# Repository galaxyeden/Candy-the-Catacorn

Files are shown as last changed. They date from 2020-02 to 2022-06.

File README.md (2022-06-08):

# Candy the Catacorn 🐱 + 🦄

[Update - I'm currently planning a board revision to make this easier to make with more obtainable parts]

Catacorn Badge :D I don't care how you spell it, I've spelled it catacorn for years. Caticorn is equally valid! It's really small, and cute - but you should be able to program it to do a lot of things.

You can [order from OSH Park](https://oshpark.com/shared_projects/pnVDiM8w) - that's not a sponsored link, and they're by no means the cheapest place to order from, I only link as they're probably the cheapest way to get a small number of purple boards with a lead-free finish (good as they'll be handled!) - and their service has always been good to me.

## Background

I have wanted to learn more about electrical engineering and the 'hardware' side of things, so have started playing with dev boards including the Adafruit Trinket M0, which is the board that inspired this project. But none of them were catacorn enough, so I decided to make one :)

## Copyright/Liability

I'm not a lawyer, I believe everything I've based this on is licensed in a way I can draw inspiration, but let me know if you want me to get rid of something. All my work is Creative Commons, see license file. Also, I'm obviously not responsible for injuries or anything like that - this is definitely not a safety-tested, commercial project. Build at your own risk. It probably won't even work :)

## Basic Features

- ATSAMD21 microcontroller (ARM Cortext M0)
- Lots of LEDs, including two RGB ones (Dotstar-compatible)
- Two capacitive touch zones (ears)
- Native USB (you can even use it as a keyboard, hopefully)
- Probably a fair number of bugs and bad design decisions!

## Bill of Materials

| Component | Manufacturer | Qty |
|---|---|-----|
| This board | Whoever you choose | 1 |
| ATSAMD21E18A-AU-ND | Microchip Technology | 1 |
| S2B-PH-SM4-TB(LF)(SN) | JST | 1 |
| 1uF 0603 Capacitor | Any | 2 |
| 10uF 0603 Capacitor | Any | 2 |
| APA102-5050 or Equivalent (e.g. SK9822) | APA Electronic Co (or other) | 2 |
| JE2835AWT-00-0000-000A0ZF940E | Cree Inc | 2 |
| Pink LED 0805 | Generic | 2 |
| Turquoise LED 0805 | Generic | 3 |
| UV/Purple LED 0805 | Generic | 3 |
| AP2112K-3.3TRG1 | Diodes Incorporated | 1 |
| DSS14UTR | SMC Diode Solutions | 2 |
| USB3076-30-A | GCT | 1 |
| 150 Ohm 1206 Resistor | Any | 2 |
| 180 Ohm 0805 Resistor | Any | 2 |
| 180 Ohm 0603 Resistor | Any | 3 |
| 330 Ohm 0805 Resistor | Any | 3 |
| TL3342 Switch (or equivalent) | E-Switch (or generic) | 1 |

## How to use?

This board is intended to be used with either CircuitPython or [PlatformIO](https://platformio.org/). I have cloned and modified others [bootloader](https://github.com/MermaidAllie/uf2-samdx1/tree/master/build/alliecat_candythecatacorn) and [CircuitPython firmware](https://github.com/MermaidAllie/circuitpython/blob/5.0.x/ports/atmel-samd/build-alliecat_candythecatacorn/firmware.uf2). These are very similar to the Adafruit Trinket M0, just rebranded basically, and you can use Adafruit Trinket M0 bootloader/firmware with a lot of success (it's how I prototyped this).

I have also included PlatformIO code and board configuration.

## Thanks

Thank you to the following people:

- Ladyada and [Adafruit](https://learn.adafruit.com/how-to-program-samd-bootloaders/trinket-m0-wiring) - for building excellent products and teaching people electronics. I used a lot of Trinket M0's in prototyping this. Seriously, people, go buy their products - they're fantastic (and the boards are way cuter than some others, especially look at the Metro M4 Express - it's just adorable).

- Various inspirations for the catacorn, but especially to the kid who asked me to paint their face as a catacorn when I was face painting some years ago. It was the first time I really started thinking what the features of a catacorn should be like. I hope you're doing well today, and I wish you all the best in life :) - also to the many people who've drawn catacorns (and caticorns and unicats) online, and I've taken inspiration from.

- Also, on that note, credit to [Lisa Frank](https://lisafrank.com/) because cute Lisa Frank images were one of my childhood inspirations, and they're just awesome and made me like this style of art. A Google image search gave me more ideas for how to draw the board outline and even how to place components to be part of the art (e.g. using a capacitor as a nose, as one drawing I found had a very square nose). The purple Lisa Frank cat, especially, gave me the idea for how the whiskers could work on a component-kitty. And, only in Lisa Frank land do RGB LED cat eyes make sense :) 

- I found [this image from Freepik](https://www.freepik.com/free-vector/kawaii-style-unicorn-character-collection_4697393.htm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) which gave me inspiration for the general shape of the base (I needed something flatter than most to get the micro USB port in, and I liked how the cat's belly sat down) and head angle of the catacorn, and also for the style of the heart outline on the cheek. That said, Candy isn't a clone of anyone else's catacorn, with her tiny little horn and big glowing glittery heart, she has her own place in the world - and many others also provided inspiration. So credit to everyone who's drawn a catacorn that's in the first few pages of Google Images results :D

- [Emojipedia](https://emojipedia.org/) came in really useful to for bits of emoji-inspired inspiration, and the capacitive touch zones (which are the heart emoji from a font on my system).

- Q - for being an awesome friend who has helped with so much of the EDA side of working this all out. Thank you for answering late night messages with silly questions!

- Charlie - for coming up with the name Candy! I love you bestie :D Without your encouragement and inspiration, I wouldn't have achieved half the things I have with tech. Thank you <3

- JoJo Siwa - because the inspirational quote comes from one of your songs, and your concert on the [D.R.E.A.M. tour](https://www.jojodreamtour.com/) I went to in Cardiff was amazing. I'm not sure if it's your original quote tho, so I didn't quote it as you - I think I've heard it before? Either way, very inspiring performance! Keep things fun and positive and spread the positive energy, people!

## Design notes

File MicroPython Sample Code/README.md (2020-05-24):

# MicroPython Sample Code

This directory contains sample MicroPython files designed to run on [NyanPython](https://github.com/GalaxyAllie/nyanpython) (a fork of [CircuitPython](https://github.com/adafruit/circuitpython)).

## How to use

Rename the file to 'main.py' and copy to the NYANPY drive.

## Contributions Welcome!

Please add both your file and a description in this readme to your pull request 🧜‍♀️

## List of files

### purpletwinkle.py

The original demo file by @GalaxyAllie - this file is a demo of the capacitive touch and LEDs.

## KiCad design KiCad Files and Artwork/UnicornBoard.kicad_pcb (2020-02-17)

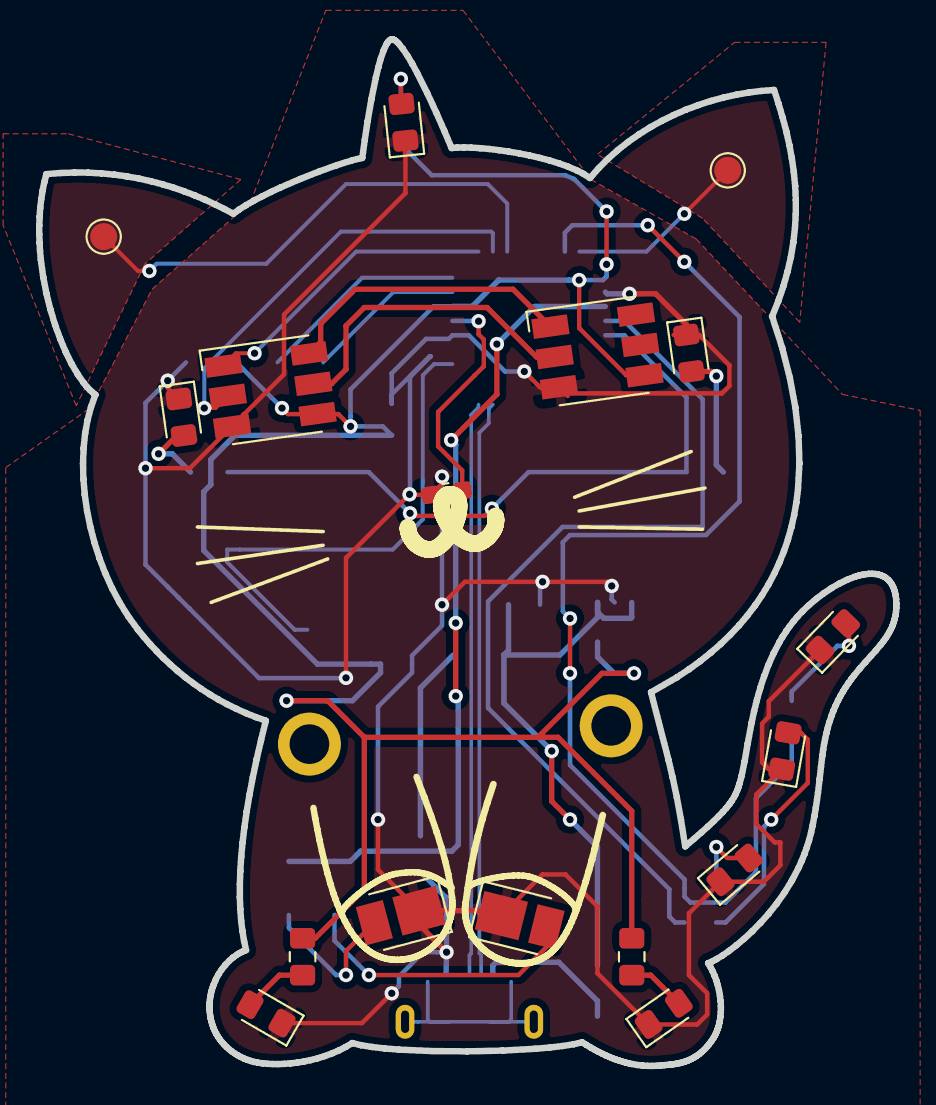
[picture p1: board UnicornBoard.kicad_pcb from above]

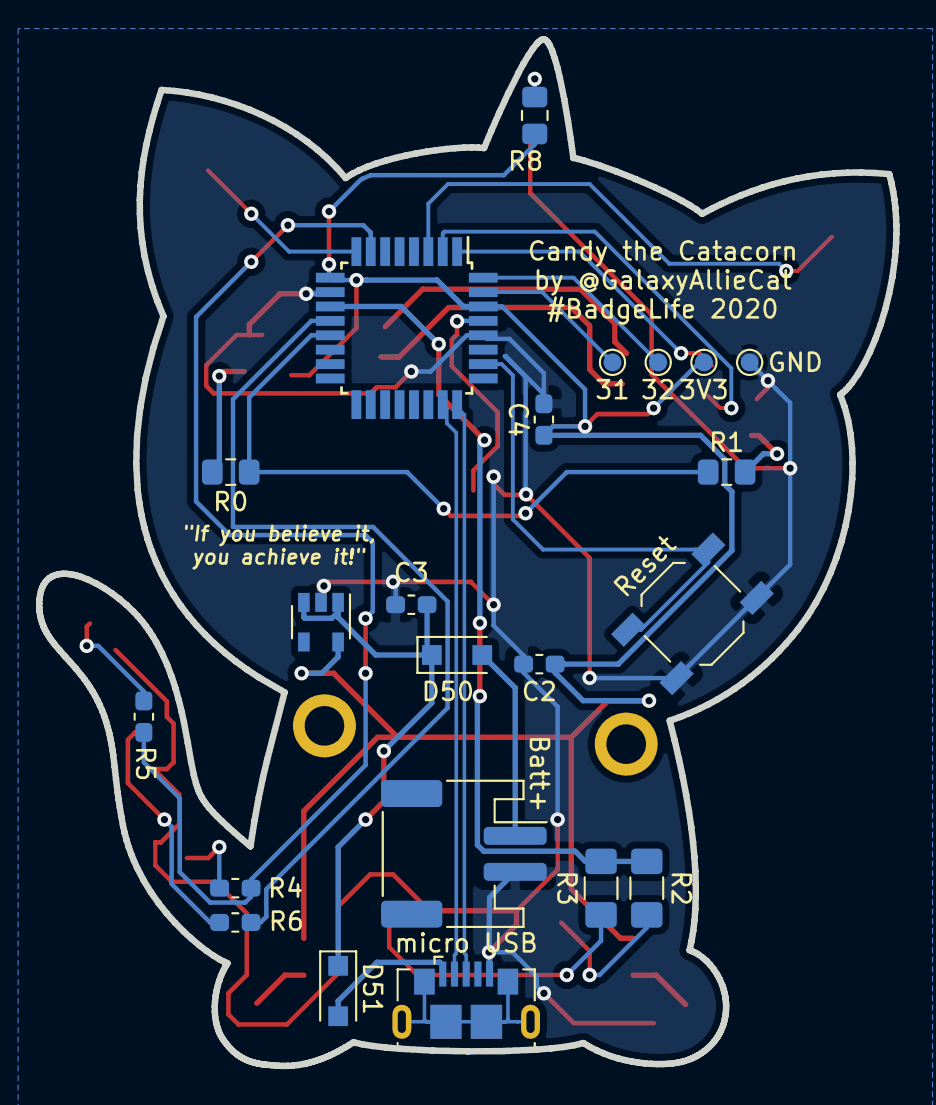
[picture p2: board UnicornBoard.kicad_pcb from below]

Board: 2 copper layers, 47.6 x 57.0 mm, 41 parts (22 on the bottom side), 31 nets.

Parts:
3V3, 31, 32: Conn_01x01; TestPoint_Pad_D1.0mm
Batt+: Battery; JST_PH_S2B-PH-SM4-TB_1x02-1MP_P2.00mm_Horizontal
C1, C4: 1 uF C; C_0603_1608Metric_Pad1.05x0.95mm_HandSolder
C2, C3: 10 uF C; C_0603_1608Metric_Pad1.05x0.95mm_HandSolder
D0, D1, D4, D5, D6, D7, D8, D9: LED; LED_0805_2012Metric_Pad1.15x1.40mm_HandSolder
D2, D3: LED; LED_PLCC_2835_Handsoldering
D50, D51: D_Schottky; D_SOD-123F
Dot1, Dot2: APA102; LED_RGB_5050-6
GND: Conn_01x01; TestPoint_Pad_D1.0mm
H1, H2: MountingHole; MountingHole_2.2mm_M2_ISO7380_Pad
R0, R1: 180R; R_0805_2012Metric_Pad1.15x1.40mm_HandSolder
R2, R3: 30R; R_1206_3216Metric_Pad1.42x1.75mm_HandSolder
R4, R5, R6: 100R; R_0603_1608Metric_Pad1.05x0.95mm_HandSolder
R7, R8, R9: 330R; R_0805_2012Metric_Pad1.15x1.40mm_HandSolder
Reset: SW_Push; SW_SPST_TL3342
Touch1, Touch2: MountingHole_Pad; TestPoint_Pad_D1.5mm
U1: ATSAMD21E18A-AU; TQFP-32_7x7mm_P0.8mm
U2: AP2112K-3.3; SOT-23-5
micro USB: USB_B_Micro; USB_Micro-B_GCT_USB3076-30-A

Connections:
+3V3: 3V3.1, C2.2, C4.1, Dot1.4, Dot2.4, R7.1, R8.1, R9.1, U1.9, U1.30, U2.5
+BATT: Batt+.1, D50.2
/USB_D+: U1.24, micro USB.3
/USB_D-: U1.23, micro USB.2
GND: Batt+.2, C1.1, C2.1, C3.2, C4.2, D0.1, D1.1, D2.1, D3.1, D4.1, D5.1, D6.1, D7.1, D8.1, D9.1, Dot1.3, Dot2.3, GND.1, Reset.2, U1.10, U1.28, U2.2, micro USB.5
unnamed: C1.2, U1.29
unnamed: C3.1, D50.1, D51.1, U2.1, U2.3
unnamed: D0.2, R0.2
unnamed: D1.2, R1.2
unnamed: D2.2, R2.1
unnamed: D3.2, R3.1
unnamed: D4.2, R4.2
unnamed: D5.2, R5.2
unnamed: D6.2, R6.2
unnamed: D7.2, R7.2
unnamed: D8.2, R8.2
unnamed: D9.2, R9.2
unnamed: Dot1.1, Dot2.6
unnamed: Dot1.2, Dot2.5
unnamed: Dot2.1, U1.1
unnamed: Dot2.2, U1.2
unnamed: 31.1, U1.31
unnamed: 32.1, U1.32
unnamed: R0.1, R1.1, U1.13
unnamed: R2.2, R3.2, U1.11
unnamed: R4.1, R5.1, U1.7
unnamed: R6.1, U1.12
unnamed: Reset.1, U1.26
unnamed: Touch1.1, U1.8
unnamed: Touch2.1, U1.3
VBUS: D51.2, micro USB.1

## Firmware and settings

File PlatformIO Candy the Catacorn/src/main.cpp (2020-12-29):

// C++ demo program for Candy the Catacorn
// https://galaxyallie.space/Candy-the-Catacorn/

#include <Arduino.h>
#include <SPI.h>
#include <Adafruit_DotStar.h>
#include <Adafruit_FreeTouch.h>
#include <adafruit_ptc.h>
#include <samd21_ptc_component.h>

#define NUMSTARS 2
#define STARDATA 7
#define STARCLOCK 8

int moving = 0;
int initialRTouchValue = 0;
int RtouchValue = 0;
int initialLTouchValue = 0;
int LtouchValue = 0;
int n = 30;
int k = 1;
int d = 1;
int i = 30;
int j = 255;
int modeSel = 0;
int light = 0;
int rtime = 0;
bool rainbowActive = false;

// Configure DotStar eyes and Adafruit FreeTouch for ears

Adafruit_DotStar stars = Adafruit_DotStar(NUMSTARS, STARDATA, STARCLOCK, DOTSTAR_BGR);
Adafruit_FreeTouch qt_1 = Adafruit_FreeTouch(A0, OVERSAMPLE_4, RESISTOR_50K, FREQ_MODE_NONE);
Adafruit_FreeTouch qt_2 = Adafruit_FreeTouch(A3, OVERSAMPLE_4, RESISTOR_50K, FREQ_MODE_NONE);

// Pin notes:
// - D0/A2 controls the white lights on the paws
// - D1/A0 is the right ear capacitive touch sensor
// - D3/A3 is the left ear capacitive touch sensor
// - D2/A1 is the first tail section
// - D4/A4 is the second tail section 
// - D13 is the corner of the eyes
// - The eyes are the internal DotStar pin

void setup() {
  Serial.begin(115200); // USB serial is used for diagnostics messages
  pinMode(13, OUTPUT); // Eye corners
  pinMode(0, OUTPUT); // White front paws
  pinMode(2, OUTPUT); // Tail section one
  pinMode(4, OUTPUT); // Tail section two
  stars.setBrightness(191); // 75% max brightness to reduce heat and aging of DotStars
  stars.begin();
  stars.show();
  if (! qt_1.begin()) {
    Serial.println("Failed to begin qt on pin A0");
  }
  if (! qt_2.begin()) {
    Serial.println("Failed to begin qt on pin A3");
  }
  initialRTouchValue = qt_1.measure();
  initialLTouchValue = qt_2.measure();
}

// Capacitive touch detection function for right ear (Candy's right)

bool RcapTouchDetect() {
    Serial.println("\n*** Touch Result ***");
    rtime = millis();
    RtouchValue = qt_1.measure(); 
    Serial.print("Right Ear: "); Serial.print(RtouchValue);
    Serial.print(" (");  Serial.print(millis() - rtime); Serial.println(" ms)");   
    if(RtouchValue > (initialRTouchValue + 100)){
        return true;
    }
    else{
        return false;
    }
}

// Capacitive touch detection function for left ear (Candy's left)

bool LcapTouchDetect() {
    Serial.println("\n*** Touch Result ***");
    rtime = millis();
    LtouchValue = qt_2.measure(); 
    Serial.print("Left Ear: "); Serial.print(LtouchValue);
    Serial.print(" (");  Serial.print(millis() - rtime); Serial.println(" ms)");   
    if(LtouchValue > (initialLTouchValue + 100)){
        return true;
    }
    else{
        return false;
    }
}

// Light show for main loop

void lightShow(int light) {
  if (light == 0)
  {
    n = n + k;
    if (n > 255)
    {
      k = -1;
      n = 255;
    }
    if (n < 30)
    {
      k = 1;
      n = 30;
    }
    for(int pixelSel = 0; pixelSel < NUMSTARS; pixelSel++){
      stars.setPixelColor(pixelSel, 10, 0, ((n / 12) + 3));
    }
    stars.show();
    analogWrite(13, (n / 8));
    analogWrite(0, (n / 20));
    analogWrite(2, (n / 8));
    analogWrite(4, (n / 8));
    delay(10);
  }
  if (light == 1)
  {
    n = n + k;
    if (n > 255)
    {
      k = -1;
      n = 255;
    }
    if (n < 30)
    {
      k = 1;
      n = 30;
    }
    for(int pixelSel = 0; pixelSel < NUMSTARS; pixelSel++){
      stars.setPixelColor(pixelSel, 0, ((n / 12) + 3), 15);
    }
    stars.show();
    analogWrite(13, (n / 8));
    analogWrite(0, (n / 20));
    analogWrite(2, (n / 8));
    analogWrite(4, (n / 8));
    delay(10);
  }
  if(light == 2)
  {
    for(int pixelSel = 0; pixelSel < NUMSTARS; pixelSel++){
      stars.setPixelColor(pixelSel, 5, 0, 5);
    }
    stars.show();
    analogWrite(13, 10);
    analogWrite(0, 255);
    analogWrite(2, 10);
    analogWrite(4, 10);
  }
  if(light == 3)
  {
    for(int pixelSel = 0; pixelSel < NUMSTARS; pixelSel++){
      stars.setPixelColor(pixelSel, 0, 10, 15);
    }
    stars.show();
    analogWrite(13, 10);
    analogWrite(0, 255);
    analogWrite(2, 10);
    analogWrite(4, 10);
  }
}

// Rainbow generator

void rainbowTime () {
  while (rainbowActive == true)
  {
    analogWrite(13, 2);
    analogWrite(0, 2);
    analogWrite(2, 2);
    analogWrite(4, 2);
    for(long rainBowStarColour = 28672; rainBowStarColour < 94207 && rainbowActive == true; rainBowStarColour += 256) 
    {
      uint32_t rainBowSel = stars.gamma32(stars.ColorHSV(rainBowStarColour));
        for(int pixelSel = 0; pixelSel < NUMSTARS && rainbowActive == true; pixelSel++)
        {
            stars.setPixelColor(pixelSel, rainBowSel);
        }
        stars.show();
        if(RcapTouchDetect() == false)
        {
          delay(30);
          if(RcapTouchDetect() == false)
          {
            rainbowActive = false;
          }
        }
        delay(40);
    }
    if(RcapTouchDetect() == false)
    {
      delay(30);
      if(RcapTouchDetect() == false)
      {
        rainbowActive = false;
      }
    }
  }
}

void loop() {
  if(RcapTouchDetect() == true) // Right ear rainbow mode!!!
  {
    delay(50);
    if(RcapTouchDetect() == true)
    {
        rainbowActive = true;
        rainbowTime();
    }      
  }
  if(LcapTouchDetect() == true) // Left ear mode switch
  {
    delay(50);
    if(LcapTouchDetect() == true)
    {
      modeSel++;
      if(modeSel > 3)
      {
        modeSel = 0;
      }
      delay(300);
    }
  };
  lightShow(modeSel);
}

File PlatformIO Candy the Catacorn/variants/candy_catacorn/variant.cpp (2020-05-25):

/*
  Copyright (c) 2014-2015 Arduino LLC.  All right reserved.

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
  You should have received a copy of the GNU Lesser General Public
  License along with this library; if not, write to the Free Software
  Foundation, Inc., 51 Franklin St, Fifth Floor, Boston, MA  02110-1301  USA
*/

#include "variant.h"

/*
 * Pins descriptions
 */
const PinDescription g_APinDescription[]=
{
  // GPIO 0-4 on external pads
  // D0, ADC, PWM, IRQ, and I2C SDA on sercom2 - no captouch
  { PORTA,  8, PIO_SERCOM_ALT, (PIN_ATTR_DIGITAL|PIN_ATTR_PWM|PIN_ATTR_TIMER), ADC_Channel16, PWM0_CH0, TCC0_CH0, EXTERNAL_INT_NMI },  // TCC0/WO[0]

  // D1, ADC, DAC, IRQ, Captouch and general purpose pin - no timer
  { PORTA,  2, PIO_ANALOG, PIN_ATTR_ANALOG, ADC_Channel0, NOT_ON_PWM, NOT_ON_TIMER, EXTERNAL_INT_2 }, // ADC/AIN[0]

  // D2, ADC, PWM, IRQ, and I2C SCL on sercom2 - no captouch
  { PORTA,  9, PIO_SERCOM_ALT, (PIN_ATTR_DIGITAL|PIN_ATTR_PWM|PIN_ATTR_TIMER), ADC_Channel17, PWM0_CH1, TCC0_CH1, EXTERNAL_INT_9 }, // TCC0/WO[1]

  // D3, ADC, PWM, IRQ, UART RX, Captouch and general purpose pin
  { PORTA,  7, PIO_SERCOM_ALT, (PIN_ATTR_DIGITAL), ADC_Channel7, NOT_ON_PWM, NOT_ON_TIMER, EXTERNAL_INT_7 }, // TCC1/WO[1]

  // D4, ADC, PWM, IRQ, UART TX, Captouch and general purpose pin
  { PORTA,  6, PIO_SERCOM_ALT, (PIN_ATTR_DIGITAL|PIN_ATTR_PWM|PIN_ATTR_TIMER), ADC_Channel6, PWM1_CH0, TCC1_CH0, EXTERNAL_INT_6 }, // TCC1/WO[0]

  // D5, same as D0 but on sercom2 (for SPI sercommin')
  { PORTA,  8, PIO_SERCOM, (PIN_ATTR_DIGITAL|PIN_ATTR_PWM|PIN_ATTR_TIMER), ADC_Channel16, PWM0_CH0, TCC0_CH0, EXTERNAL_INT_NMI },  // TCC0/WO[0]
  // D6, same as D2 but on sercom2 (for SPI sercommin')
  { PORTA,  9, PIO_SERCOM, (PIN_ATTR_DIGITAL|PIN_ATTR_PWM|PIN_ATTR_TIMER), ADC_Channel17, PWM0_CH1, TCC0_CH1, EXTERNAL_INT_9 }, // TCC0/WO[1]

  // GPIO 7 & 8 - DotStar internal data/clock
  // ----------------------------------------
  { PORTA,  0, PIO_DIGITAL, 0, ADC_Channel4, NOT_ON_PWM, NOT_ON_TIMER, EXTERNAL_INT_4 }, // ADC/AIN[4]
  { PORTA,  1, PIO_DIGITAL, 0, ADC_Channel5, NOT_ON_PWM, NOT_ON_TIMER, EXTERNAL_INT_5 }, // ADC/AIN[5]

  // GPIO 9, 10, 11 USB Host enable
  // ----------------------------
  { PORTA, 28, PIO_COM, PIN_ATTR_NONE, No_ADC_Channel, NOT_ON_PWM, NOT_ON_TIMER, EXTERNAL_INT_NONE }, // USB Host enable - GPIO #5
  { PORTA, 24, PIO_COM, PIN_ATTR_NONE, No_ADC_Channel, NOT_ON_PWM, NOT_ON_TIMER, EXTERNAL_INT_NONE }, // USB/DM - GPIO #6
  { PORTA, 25, PIO_COM, PIN_ATTR_NONE, No_ADC_Channel, NOT_ON_PWM, NOT_ON_TIMER, EXTERNAL_INT_NONE }, // USB/DP - GPIO #7

  // GPIO 12 is a placeholder, same as D13
  { PORTA, 10, PIO_DIGITAL, (PIN_ATTR_DIGITAL|PIN_ATTR_PWM|PIN_ATTR_TIMER), No_ADC_Channel, PWM1_CH1, TCC1_CH1, EXTERNAL_INT_10 }, // TX: SERCOM0/PAD[2]

  // GPIO 13 (LED)
  { PORTA, 10, PIO_DIGITAL, (PIN_ATTR_DIGITAL|PIN_ATTR_PWM|PIN_ATTR_TIMER), No_ADC_Channel, PWM1_CH1, TCC1_CH1, EXTERNAL_INT_10 }, // TX: SERCOM0/PAD[2]


  // Digital 14 - 18, Analog A0-A4
  // A0 same as D1
  { PORTA,  2, PIO_ANALOG, PIN_ATTR_ANALOG, ADC_Channel0, NOT_ON_PWM, NOT_ON_TIMER, EXTERNAL_INT_2 }, // ADC/AIN[0]
  // A1, same as D2
  { PORTA,  9, PIO_ANALOG, (PIN_ATTR_ANALOG|PIN_ATTR_DIGITAL|PIN_ATTR_PWM|PIN_ATTR_TIMER), ADC_Channel17, PWM0_CH1, TCC0_CH1, EXTERNAL_INT_9 }, // TCC0/WO[1]
  // A2, same as D0
  { PORTA,  8, PIO_ANALOG, (PIN_ATTR_ANALOG|PIN_ATTR_DIGITAL|PIN_ATTR_PWM|PIN_ATTR_TIMER), ADC_Channel16, PWM0_CH0, TCC0_CH0, EXTERNAL_INT_NMI },  // TCC0/WO[0]
  // A3, same as D3
  { PORTA,  7, PIO_ANALOG, (PIN_ATTR_ANALOG|PIN_ATTR_DIGITAL|PIN_ATTR_PWM|PIN_ATTR_TIMER), ADC_Channel7, PWM1_CH1, TCC1_CH1, EXTERNAL_INT_7 }, // TCC1/WO[1]
  // A4, same as D4
  { PORTA,  6, PIO_ANALOG, (PIN_ATTR_ANALOG|PIN_ATTR_DIGITAL|PIN_ATTR_PWM|PIN_ATTR_TIMER), ADC_Channel6, PWM1_CH0, TCC1_CH0, EXTERNAL_INT_6 }, // TCC1/WO[0]


  // GPIO 19 & 20 (SWCLK & SWDIO)
  // --------------------------
  { PORTA, 30, PIO_TIMER, PIN_ATTR_NONE, No_ADC_Channel, NOT_ON_PWM, NOT_ON_TIMER, EXTERNAL_INT_NONE },
  { PORTA, 31, PIO_TIMER, PIN_ATTR_NONE, No_ADC_Channel, NOT_ON_PWM, NOT_ON_TIMER, EXTERNAL_INT_NONE },


  // Placeholder #21 & 22 for 'txled' and 'rxled'
  { PORTA, 14, PIO_DIGITAL, (PIN_ATTR_DIGITAL), No_ADC_Channel, NOT_ON_PWM, NOT_ON_TIMER, EXTERNAL_INT_14 },
  { PORTA, 15, PIO_DIGITAL, (PIN_ATTR_DIGITAL|PIN_ATTR_PWM|PIN_ATTR_TIMER), No_ADC_Channel, PWM3_CH1, TC3_CH1, EXTERNAL_INT_15 },
} ;

const void* g_apTCInstances[TCC_INST_NUM+TC_INST_NUM]={ TCC0, TCC1, TCC2, TC3, TC4, TC5 } ;

// Multi-serial objects instantiation
SERCOM sercom0( SERCOM0 ) ;
SERCOM sercom1( SERCOM1 ) ;
SERCOM sercom2( SERCOM2 ) ;
SERCOM sercom3( SERCOM3 ) ;

Uart Serial1( &sercom0, PIN_SERIAL1_RX, PIN_SERIAL1_TX, PAD_SERIAL1_RX, PAD_SERIAL1_TX ) ;

void SERCOM0_Handler()
{
  Serial1.IrqHandler();
}

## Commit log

2020-01-17 First Version
    [UnicornBoard.kicad_pcb, UnicornBoard.sch]
2020-01-30 Candy the Catacorn
    [UnicornBoard.kicad_pcb, UnicornBoard.sch]
2020-01-31 Added BOM and tweaked resistor values to keep current in spec for GPIO pins
    [UnicornBoard.sch]
2020-01-31 Added inspirational quote to back silkscreen
    [UnicornBoard.kicad_pcb]
2020-01-31 Added zipped gerbers to make easier to order
    [UnicornBoard.kicad_pcb]
2020-02-11 Removed random no connect flags
    [UnicornBoard.sch]
2020-02-11 Fixed BOM
2020-02-16 Version 2, new outline
    [UnicornBoard.kicad_pcb]
2020-02-16 Minor silk revision
    [UnicornBoard.kicad_pcb]
2020-05-24 Re-organise and setup for move to PlatformIO
    [UnicornBoard.kicad_pcb, UnicornBoard.sch]
2020-05-24 Removed zephyr framework option
2020-05-24 Minimal Working C++
    [trinket_m0.cfg]
2020-05-25 custom variant with working PWM eyes
2020-05-25 Corrected colour order, added mode
    [main.cpp]
2020-05-25 Improved rainbow, fixed blackout
    [main.cpp]
2020-06-25 noted pin functions
